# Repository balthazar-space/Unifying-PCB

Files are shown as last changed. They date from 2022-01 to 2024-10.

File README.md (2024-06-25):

# Balthazar

Open-hardware laptop computer modules description and concept.

These are electronic schematic modules as presented at https://balthazar.space/wiki/Balthazar with the main aim for team access. See the [main repository](https://github.com/balthazar-space/balthazar) for other designs.

# Unifying-PCB

Unifying PCB expansion for Balthazar 

Single PCB solution for connecting the three previously designed Balthazar modules (I/O, power supply, USB 2.0, 3.0 controllers, keyboard and adding Compute Module compatible FPGA boards. Aimed at setting a compatibility standard to widely accepted hardware standards.
It has standardized 100 pin accomodating module for adding standard CM HAT modules based on ARM or FPGA 
It has GPIO expansion port, HDMI,2x USB 3.0, Ethernet RJ45 and a microSD card slot.  

It is designed to accomodate ULX4M-CM4-HAT designed by Radiona.org using HDR 100 POS SMT board to board mezzanine connectors.

dimensions: 120x80 mm
placement: right back side of Balthazar casing

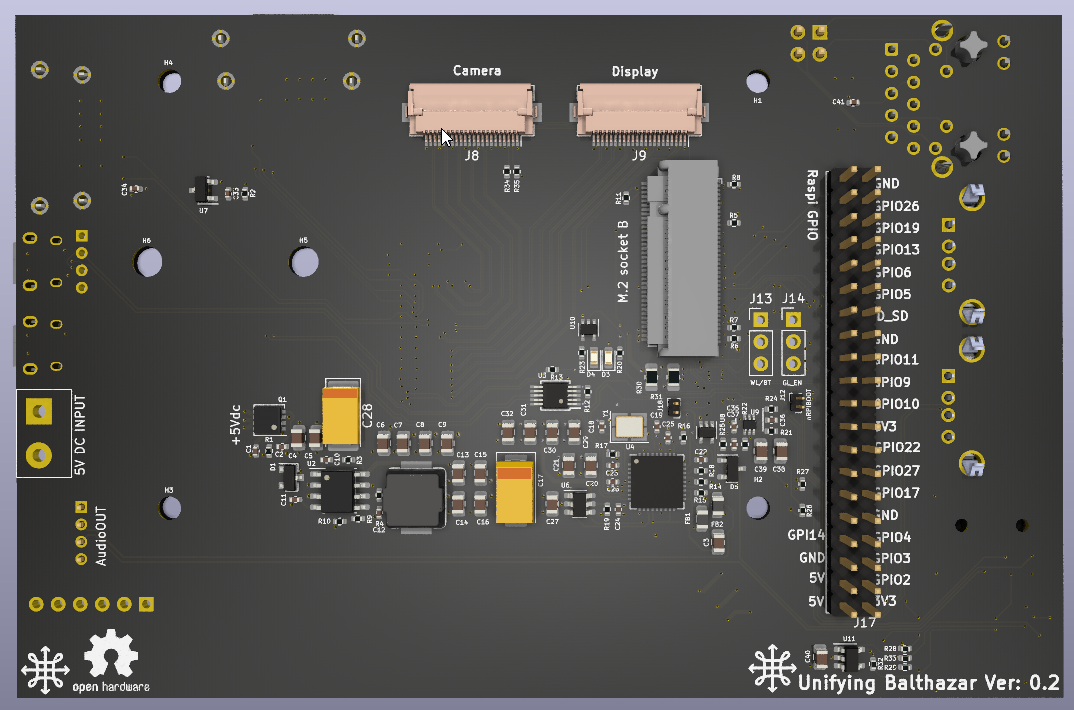
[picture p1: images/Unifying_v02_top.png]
TOP


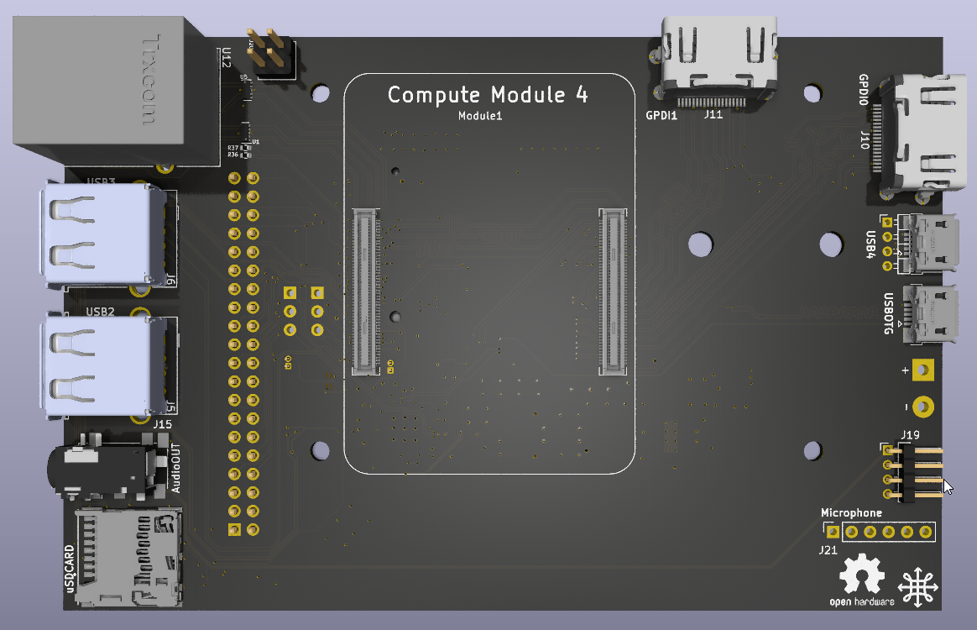
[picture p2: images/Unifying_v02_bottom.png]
BOTTOM


## License

All resources except the keyboard firmware - which is licensed with with GPLv3 or later - licensed under the CERN Open Hardware Licence CERN-OHL W V.2.0

Version 2.0 of the CERN-OHL introduces three variants of the licence – strongly (S) reciprocal, weakly (W) reciprocal and permissive (P) – which aim to address specific constraints caused by different collaboration models currently used in open-hardware projects. 

The first two variants mean that if any product is made using an open hardware design, the design of that product, including any improvements or modifications, should be made available under the same licence as that of the original product. Permissive licences do not impose this condition.

See the [LICENSE.md](./LICENSE.md) file for more information.

## Funding

This project is funded through the [NGI Zero Entrust Fund](https://nlnet.nl/entrust), a fund
established by [NLnet](https://nlnet.nl) with financial support from the European Commission's
[Next Generation Internet](https://ngi.eu) program. Learn more on the [NLnet project page](https://nlnet.nl/project/Balthazar-Casing/).

[NLNet foundation logo](https://nlnet.nl)
[NGI0 Entrust Logo](https://nlnet.nl/entrust)

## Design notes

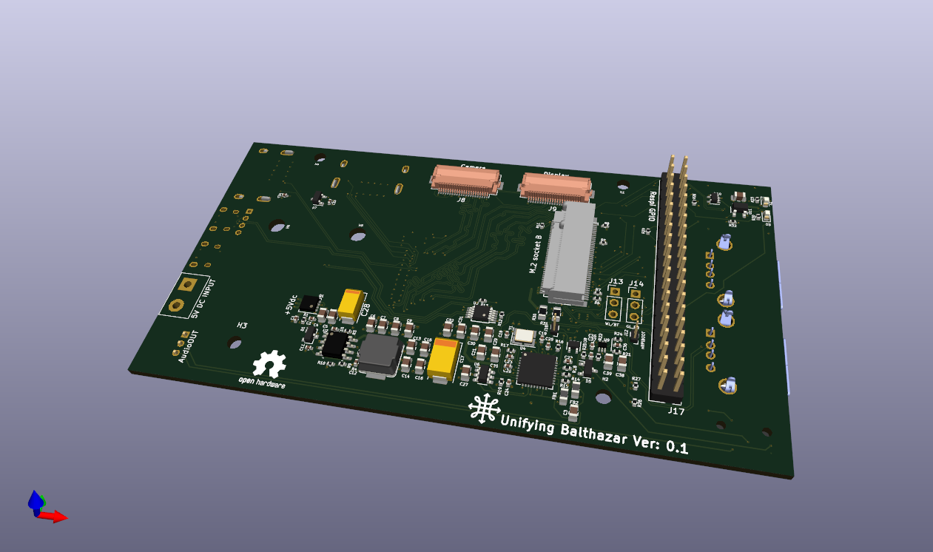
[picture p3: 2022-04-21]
images/UnifyingTOP.png

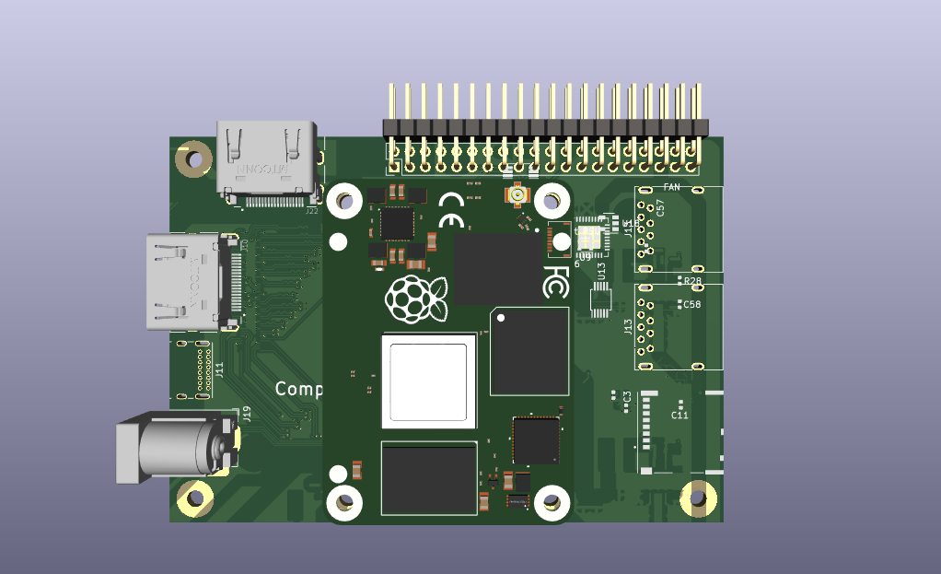
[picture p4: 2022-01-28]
images/balthazar-CM4IO-img01.png

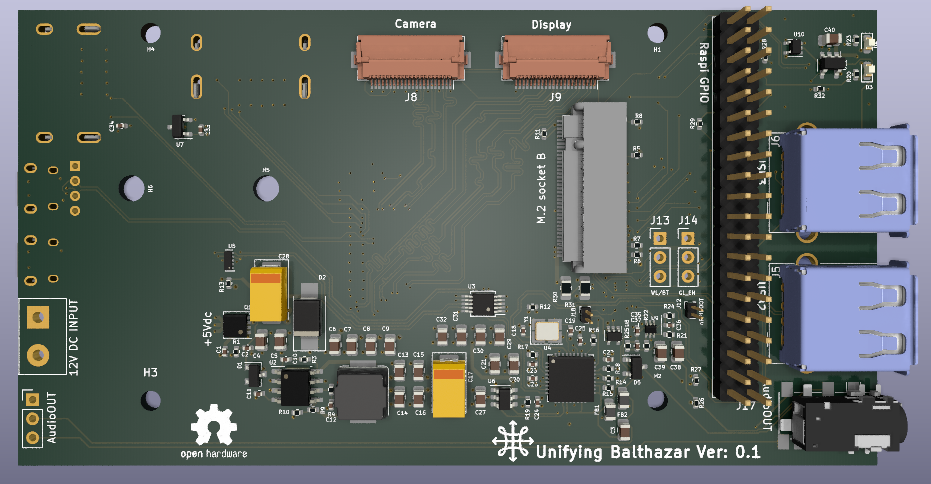
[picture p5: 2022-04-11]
images/balthazar-CM4IO-img_top.png

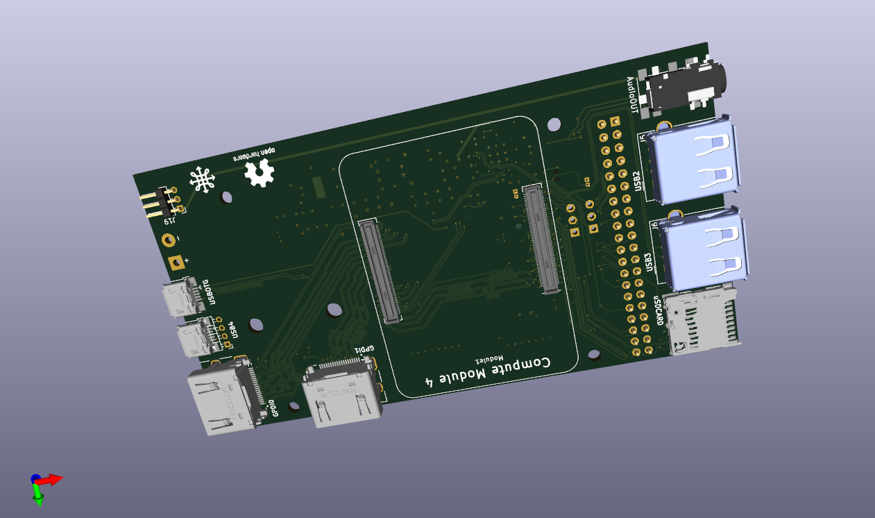
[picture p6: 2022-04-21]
images/UnifyingBOT.png

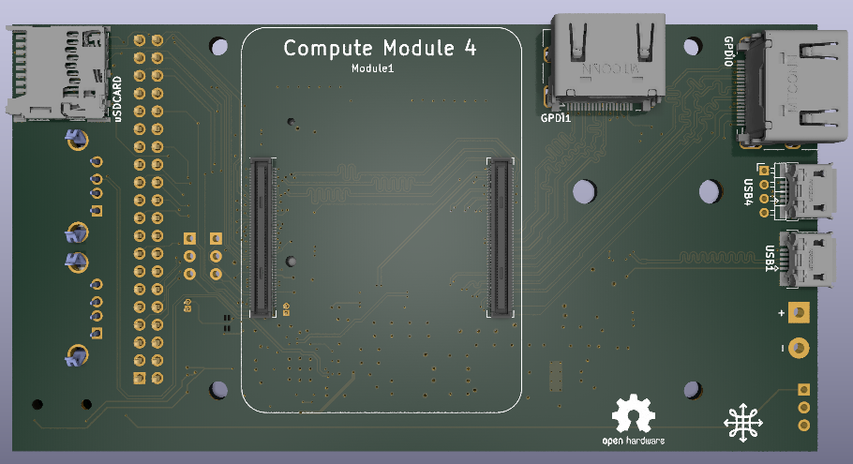
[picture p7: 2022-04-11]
images/balthazar-CM4IO-img_bottom.png

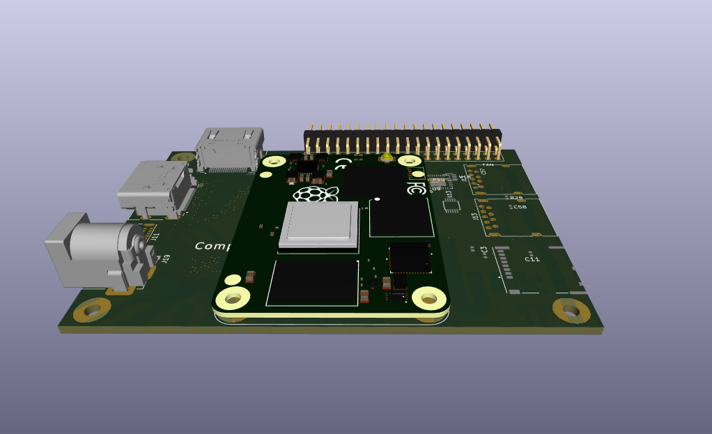
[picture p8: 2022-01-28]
images/balthazar-CM4IO-img02.png

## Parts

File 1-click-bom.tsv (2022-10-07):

References | Qty | Description | Manufacturer | MPN | Manufacturer | MPN | Digikey | Mouser | RS | Newark | Farnell | LCSC | JLC Assembly
C3, C13, C14, C15, C16, C20, C21, C27, C29, C30, C31, C32, C40 | 13 | 10u C_0805_2012Metric | KYOCERA AVX | 08053D106KAT4A |  | 08053D106KAT4A | 478-08053D106KAT4ACT-ND | 58108053D106KAT4A |  |  | 3922206
C2, C10, C11, C22, C23, C24, C25, C26, C33, C34 | 10 | 100n C_0402_1005Metric | AVX | 04025C104KAT4A |  | 04025C104KAT4A | 478-04025C104KAT4ACT-ND | 58104025C104KAT4A
C4, C5, C6, C7, C8, C9 | 6 | 10u 10v C_0805_2012Metric | Yageo | CC0805KKX5R6BB106 |  | CC0805KKX5R6BB106 | 311-1460-1-ND | 603CC805KKX5R6BB106 | 1988064 |  | 9402136
C35, C36, C37 | 3 | 100n 6.3 C_0402_1005Metric | KYOCERA AVX | 04026D104KAT4A |  | 04026D104KAT4A | 478-11504-1-ND | 58104026D104KAT4A
C18, C19 | 2 | 27pF C_0402_1005Metric |  | GCM1555C1H270FA16D |  |  |  | 81GCM1555C1H270FA6D
C38, C39 | 2 | 47u 6.3 C_0805_2012Metric | KYOCERA AVX | 08056D476MAT2A |  | 08056D476MAT2A | 478-08056D476MAT2ACT-ND | 58108056D476MAT2A
C1 | 1 | 100n 50v C_0402_1005Metric | AVX | 04025C104KAT4A |  | 04025C104KAT4A | 478-04025C104KAT4ACT-ND | 58104025C104KAT4A
C12 | 1 | 1.2nF C_0402_1005Metric | KEMET | C0402C122J5GACTU |  | C0402C122J5GACTU | 399-C0402C122J5GAC7867CT-ND | 80C0402C122J5G |  |  | 1800803
C17 | 1 | 100uF CP_EIA-7343-31_Kemet-D |  | 293D107X06R3D2TE3 |  |  |  | 74293D107X06R3D2TE3
C28 | 1 | 100uF CP_EIA-7132-20_AVX-U |  |  |  |  |  | 74293D107X06R3D2TE3
R5, R6, R7, R8, R28, R29 | 6 | nf R_0402_1005Metric
R1, R4, R17, R32 | 4 | 12K 1% R_0402_1005Metric | Vishay | PTN0402E1202BST1 |  | PTN0402E1202BST1 |  | 71PTN0402E1202BST1
R14, R15, R16, R18 | 4 | 36K 1% R_0402_1005Metric | Yageo | RT0402FRE0736KL |  | RT0402FRE0736KL | 13-RT0402FRE0736KLCT-ND | 603RT0402FRE0736KL
R10, R19 | 2 | 15K 1% R_0402_1005Metric | Yageo | RT0402FRE0715KL |  | RT0402FRE0715KL | YAG5930DKR-ND | 603RT0402FRE0715KL
R12, R13 | 2 | 2.2K 1% R_0402_1005Metric | Yageo | RT0402FRE072K2L |  | RT0402FRE072K2L | 13-RT0402FRE072K2LDKR-ND | 603RT0402FRE072K2L |  |  | 3496566
R20, R23 | 2 | 1k R_0402_1005Metric | Bourns | CRT0402-BY-1001GLF |  | CRT0402-BY-1001GLF | 118-CRT0402-BY-1001GLFCT-ND | 652CRT0402BY1001GLF
R21, R22 | 2 | 220 R_0402_1005Metric | Panasonic | ERA-2VEB2200X |  | ERA-2VEB2200X | 10-ERA-2VEB2200XDKR-ND | 667ERA2VEB2200X | 2413248 |  | 3482112
R24, R25 | 2 | 100 R_0402_1005Metric | Vishay | MCS04020D1000BE000 |  | MCS04020D1000BE000 | 749-MCS04020D1000BE000CT-ND | 594MCS04020D1000BE0
R26, R27 | 2 | 1K8 R_0402_1005Metric | TE Connectivity | CPF0402B1K8E1 |  | CPF0402B1K8E1 | A102697CT-ND | 279CPF0402B1K8E1 |  |  | 1697323
R3 | 1 | 10R R_0402_1005Metric | TE Connectivity | CPF0402B10RE1 |  | CPF0402B10RE1 | A102583DKR-ND | 279CPF0402B10RE1 | 1226344 |  | 1697292
R9 | 1 | 47K 1% R_0402_1005Metric | Yageo | AT0402FRE0747KL |  | AT0402FRE0747KL |  | 603AT0402FRE0747KL
R11 | 1 | 12K R_0402_1005Metric | Yageo | AT0402FRE0712KL |  | AT0402FRE0712KL |  | 603AT0402FRE0712KL
R30 | 1 | 0R R_0805_2012Metric_Pad1.20x1.40mm_HandSolder | Yageo | RC0603JR-070RL |  |  | 311-0.0GRCT-ND | 603RC0603JR070RL | 1995647P |  | 9233130
R31 | 1 | nf R_0805_2012Metric_Pad1.20x1.40mm_HandSolder
L2 | 1 | SRN6045TA-3R3Y | Bourns | SRN6045TA-3R3Y |  |  | SRN6045TA-3R3YCT-ND | 652SRN6045TA3R3Y |  |  | 2616889
D1 | 1 | MMBZ5242BLT3G D_SOT-23_ANK | onsemi | MMBZ5242BLT3G |  | MMBZ5242BLT3G | MMBZ5242BLT3GOSDKR-ND | 863MMBZ5242BLT3G |  |  | 3607004
D3 | 1 | LED Green LED_0603_1608Metric | Vishay | VLMTG1401-GS08 |  | VLMTG1401-GS08 | 751-VLMTG1401-GS08TR-ND | 78VLMTG1401GS08
D4 | 1 | LED Red LED_0603_1608Metric | Vishay | VLMS1300-GS08 |  | VLMS1300-GS08 | VLMS1300-GS08DKR-ND | 78VLMS1300GS08 | 7730458P |  | 2251484
D5 | 1 | BAV99 SOT-23 | Comchip | BAV99-HF |  | BAV99-HF | 641-BAV99-HFCT-ND | 750BAV99HF
U8, U10 | 2 | 74LVC1G07SE-7 | Diodes Inc. | 74LVC1G07SE-7 | Diodes Inc. | 74AHC1G126SE-7 | 74AHC1G126SE-7DIDKR-ND | 62174AHC1G126SE7 | 7512793 |  | 1893811RL
U2 | 1 | AP64501SP-13 SOIC-8-1EP_3.9x4.9mm_P1.27mm_EP2.95x4.9mm_Mask2.71x3.4mm_ThermalVias | Diodes Inc. | AP64501SP-13 |  | AP64501SP-13 | 31-AP64501SP-13CT-ND | 621AP64501SP13 |  |  | 3518317
U3 | 1 | FSUSB42MUX MSOP-10_3x3mm_P0.5mm | onsemi | FSUSB42MUX |  | FSUSB42MUX | FSUSB42MUXDKR-ND | 512FSUSB42MUX | 7395144P |  | 2564479
U4 | 1 | USB2514B | Microchip | USB2514B-AEZC-TR |  |  | USB2514B-AEZC-CT-ND | 886USB2514BAEZCTR | 1779732 |  | 2775061
U6 | 1 | AP22653W6 SOT-23-6 | Diodes Inc. | AP22653W6-7 |  | AP22653W6-7 | 31-AP22653W6-7DKR-ND | 621AP22653W67 |  |  | 3755402
U7 | 1 | RT9742SNGV | Richtek | RT9742SNGV |  |  | 1028-RT9742SNGVDKR-ND
U9 | 1 | NC7WZ16 SC-88-6_2x2.1mm | onsemi | SN74AUP2G06DCKR |  | SN74AUP2G06DCKR | 595-SN74AUP2G06DCKR | 512NC7WZ16FHX |  |  | 3609115
U11 | 1 | RT9742GGJ5 SOT-23-5 | Richtek | RT9742GGJ5 |  | RT9742GGJ5 | 1028-1436-6-ND |  |  |  | 2545875
Y1 | 1 | 24MHz Crystal_SMD_EuroQuartz_X22-4Pin_5x3.2mm |  | ECS-5032MV-240-CN-TR |  |  |  | 520-5032MV-240-CNT
FB1, FB2 | 2 | FerriteBead L_0805_2012Metric | Fair-Rite | 2508051017Y0 |  | 2508051017Y0 | 1934-1435-1-ND | 6232508051017Y0 |  |  | 1781234
Module1 | 2 | ComputeModule4 Raspberry-Pi-4-Compute-Module-noholes | Hirose | DF40C-100DS-0.4V(51) |  | DF40C-100DS-0.4V(51) | H11615TR-ND | 798DF40C100DS0.4V51 |  |  | 2427679
Q1 | 1 | DMP3013SFV-7 Diodes_PowerDI3333-8 | Diodes Inc. | DMP3013SFV-7 |  | DMP3013SFV-7 | DMP3013SFV-7DITR-ND | 621DMP3013SFV7 |  |  | 3405192
J5, J6 | 2 | USB_A USB_A_Molex_67643_Horizontal | Molex | 67643-0910 |  | 67643-0910 | WM4993-ND | 538676430910 | 8006839 |  | 1450206
J8, J9 | 2 | Conn_01x22_Female Hirose_FH12-22S-0.5SH_1x22-1MP_P0.50mm_Horizontal |  | FH12-22S-0.5SH(55) |  | FH12-22S-0.5SH(55) | HFJ122CT-ND | 798FH1222S0.5SH55 | 7727049
J10, J11 | 2 | HDMI_C_1.4 EDAC 690-019-298-412 | EDAC | 690-019-298-412 |  | 208658-1051 |  | 5382086581051
J13, J14 | 2 | Conn_01x03 PinHeader_1x03_P2.54mm_Vertical |  | 61300311121 |  |  |  | 71061300311121
J1 | 1 | Conn_01x02 TerminalBlock_bornier-2_P5.08mm |  | OQ0254500000G |  |  |  | 649OQ02545000J0G
J2 | 1 | Bus_M.2_Socket_B Conn_TE-M.2-0.5-67P-doublesided | TE Connectivity | 2199230-4 |  | 2199230-4 | A115904DKR-ND | 57121992304 | 2411331 |  | 3398678
J3 | 1 | USB_OTG USB_Micro-B_EDAC_UCON00686 |  | USB3505-30-A |  |  |  | 640USB350530A
J4 | 1 | Conn_01x04_Male PinHeader_1x04_P2.00mm_Horizontal |  | SQT-104-01-F-S-RA |  |  |  | 200SQT10401FSRA
J7 | 1 | USB_MICRO USB_Micro-B_EDAC_UCON00686 |  | 47346-0001 |  |  |  | 538-47346-0001
J12 | 1 | nRpiBoot PinHeader_1x02_P1.00mm_Vertical
J15 | 1 | AudioOUT Jack_3.5mm_PJ311_Horizontal |  | SJ-43516-SMT-TR |  |  |  | 490SJ43515RSSMTTR
J16 | 1 | Micro_SD_Card_Det SDCARD_MOLEX_503398-1892 | Molex | 503398-1892 |  | 503398-1892 | WM11190CT-ND | 5385033981892 | 8801277P |  | 2358234
J17 | 1 | THD-20-R PinHeader_2x20_P2.54mm_Vertical | Hirose | 68683-220LF |  |  |  | 64968683220LF
J18 | 1 | GLOBAL_EN PinHeader_1x02_P1.00mm_Vertical
J19 | 1 | AudioAMP PinHeader_1x04_P2.00mm_Horizontal |  | M20-9990446 |  |  |  | 855M209990446

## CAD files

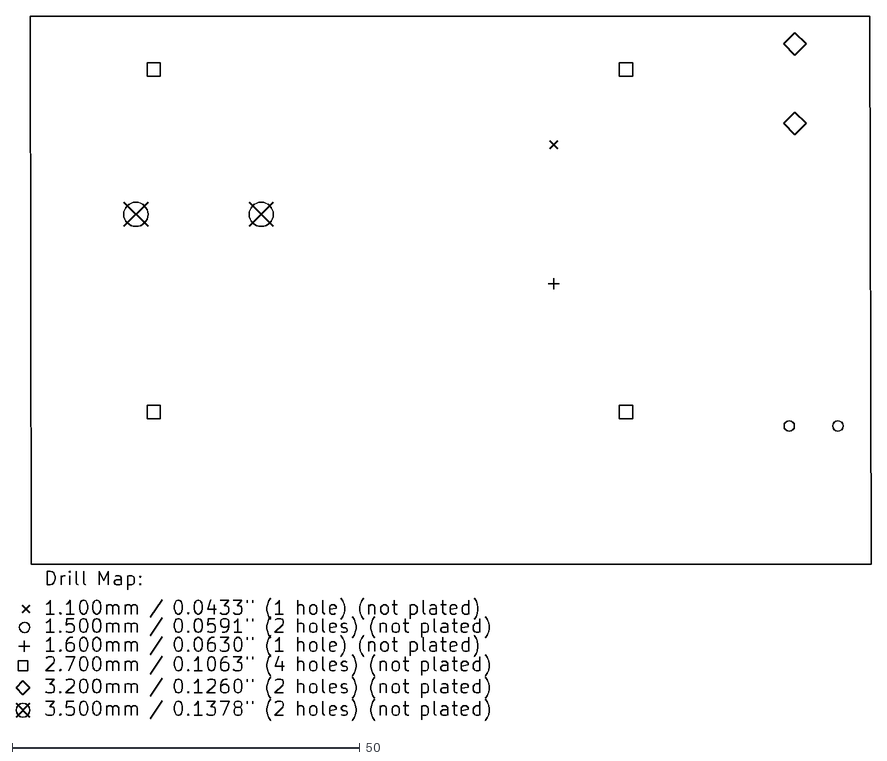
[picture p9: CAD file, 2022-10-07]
kicad/gerbers/Unifying-NPTH-drl_map.dxf
123.0 x 101.2

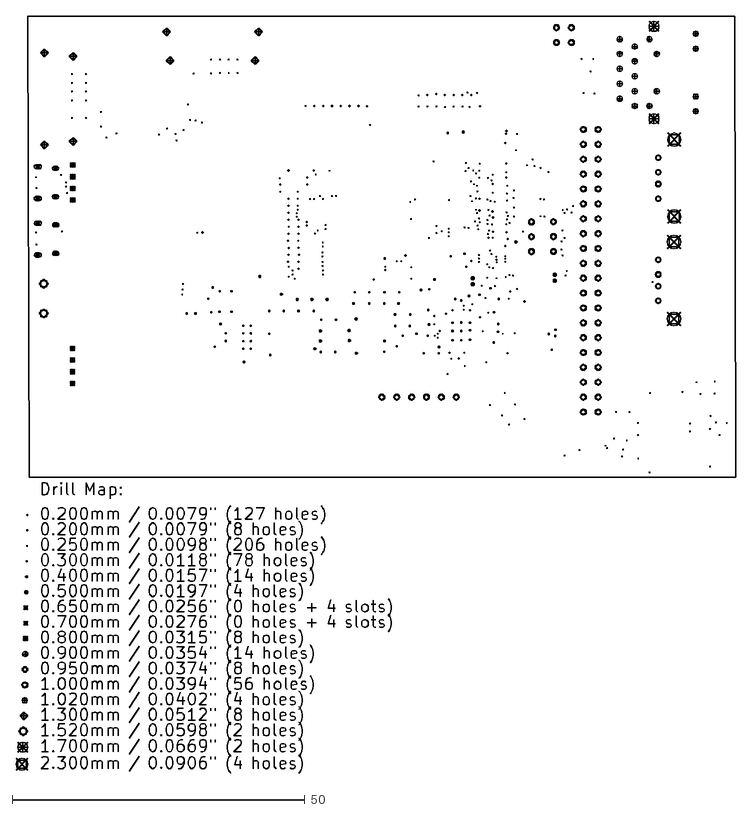
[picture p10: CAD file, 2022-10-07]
kicad/gerbers/Unifying-PTH-drl_map.dxf
123.0 x 129.3

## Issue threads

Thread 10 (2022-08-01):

USB connector is wrong in BOM

goran-mahovlic, 2022-08-01:

Closed 2022-10-07.

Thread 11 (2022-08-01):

Be aware of bricked 3.3V

goran-mahovlic, 2022-08-01:
As #5 display connector is inverted, if screen is connected 3.3V will brick to GND.
That will result in burning CM4 power supply chip.

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

goran-mahovlic, 2022-10-05:
DSI connector was rotated, this should be fixed in V02

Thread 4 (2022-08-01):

CAM - DISPL I2C is missing pullups (SDA0, SCL0)

goran-mahovlic, 2022-08-01:

Closed 2022-10-06.

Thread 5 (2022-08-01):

DISP and CAM connectors are mirrored

goran-mahovlic, 2022-08-01:
On schematics we need to vertical mirror connector.
On PCB that will be horizontal mirror.

goran-mahovlic, 2022-08-01:
Quick fix should look something like this
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

Closed 2022-10-05.

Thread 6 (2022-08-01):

Bottom side of the board was missing silkscreen

goran-mahovlic, 2022-08-01:

goran-mahovlic, 2022-10-06:
Silk screen layer is now turned on

Closed 2022-10-06.

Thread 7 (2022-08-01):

HDMI quality is really bad

goran-mahovlic, 2022-08-01:
I can hardly get any picture.

I have connected 5V directly to HDMI - usually we are using switch - maybe that added noise.

If not then we need to rework fast HDMI lines.

goran-mahovlic, 2022-10-06:
Should be fixed now, it was bad because wrong footprint

Closed 2022-10-06.

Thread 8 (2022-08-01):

Y1 in BOM list has wrong footprint

goran-mahovlic, 2022-08-01:

Closed 2022-10-07.

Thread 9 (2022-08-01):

U9 in a BOM list has wrong footprint

goran-mahovlic, 2022-08-01:

Closed 2022-10-07.

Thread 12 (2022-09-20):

HDMI has wrong footprint/simbol

goran-mahovlic, 2022-09-20:
I have recheck all connections and they are fine, but connector we have placed needs different connections...

I can see that first diff pair on CM4 IO board starts from pin1 and on our board with same connector starts from pin2 ...

We need to change symbol or footprint that will probably also  solve  #7

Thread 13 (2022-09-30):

Ethernet connector is missing

goran-mahovlic, 2022-09-30:
If there is enough space we should add one

Closed 2022-10-06.

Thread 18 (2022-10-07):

For EMC it would be best if we could switch to 6 leyer board

goran-mahovlic, 2022-10-07:
May not be important right now, but signal integrity would be improved if we switch to 6 layer board.
Currently some GPIO pins are routed on Power layer.
As we have only one GND plane signals on TOP layer are closer to the GND layer then those on BOTTOM layer...

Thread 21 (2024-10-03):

Printed schematics

prasimix, 2024-10-03:
It would be good if there were schematics so that one does not necessarily need to have KiCad installed to see it. I also suggest that in addition to or instead of print, you also make a plot in pdf, because such a version is searchable.

Closed 2024-10-17.

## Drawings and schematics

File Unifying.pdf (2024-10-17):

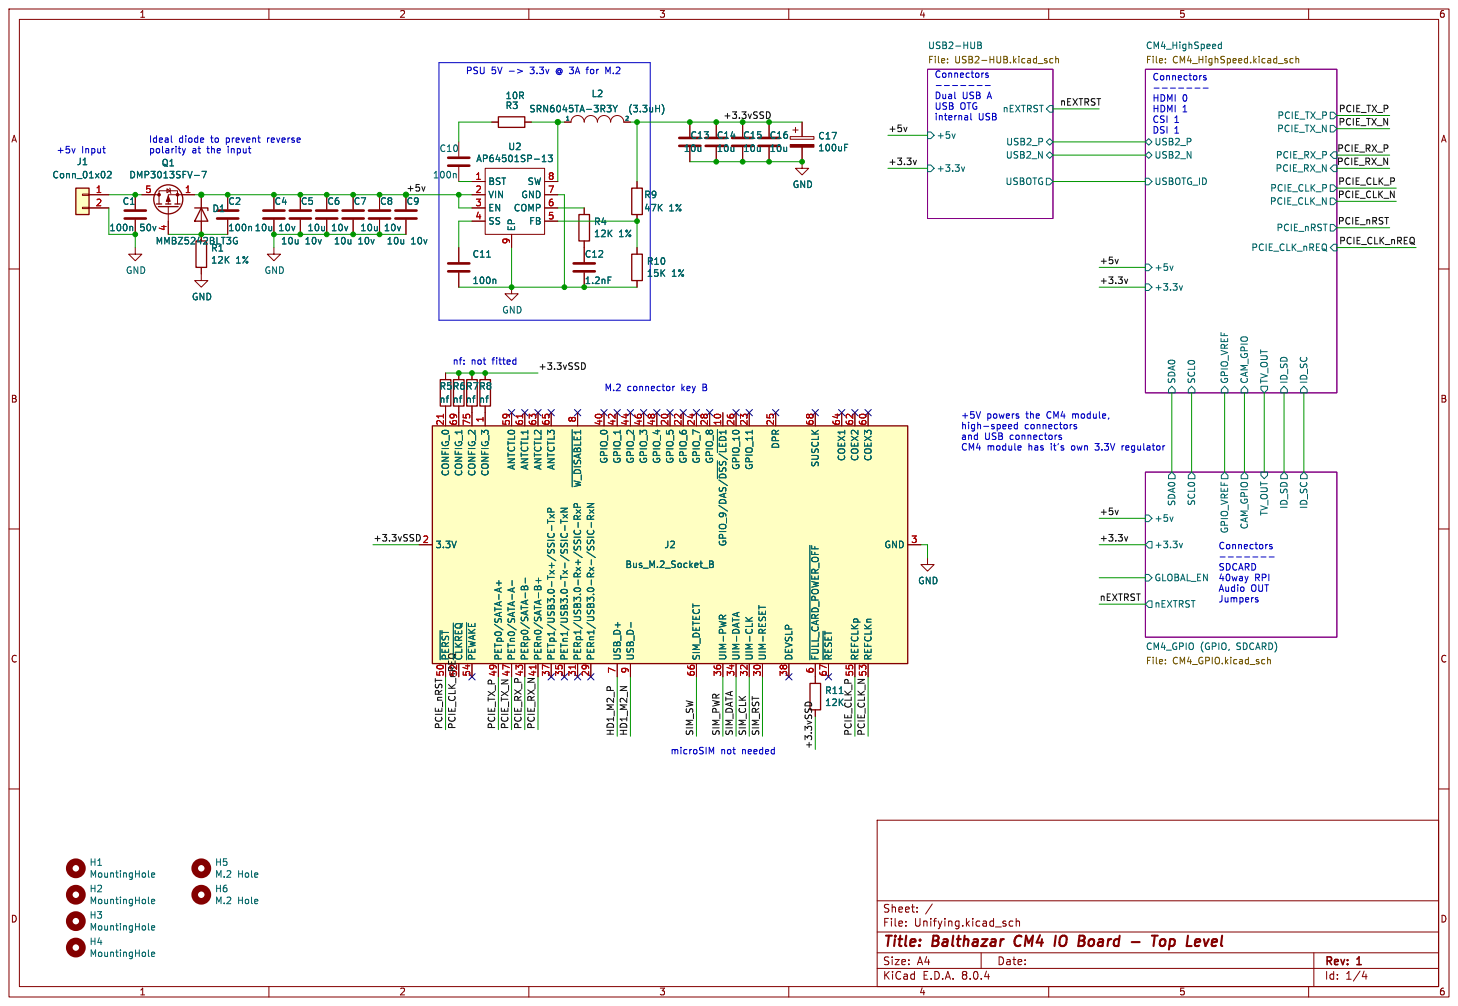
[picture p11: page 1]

------- Dual USB A USB OTG

Ideal diode to prevent reverse
5 Q1 DMP3013SFV-7 C1

Id: 1/4 Title: Balthazar CM4 IO Board - Top Level File: Unifying.kicad_sch Sheet: /

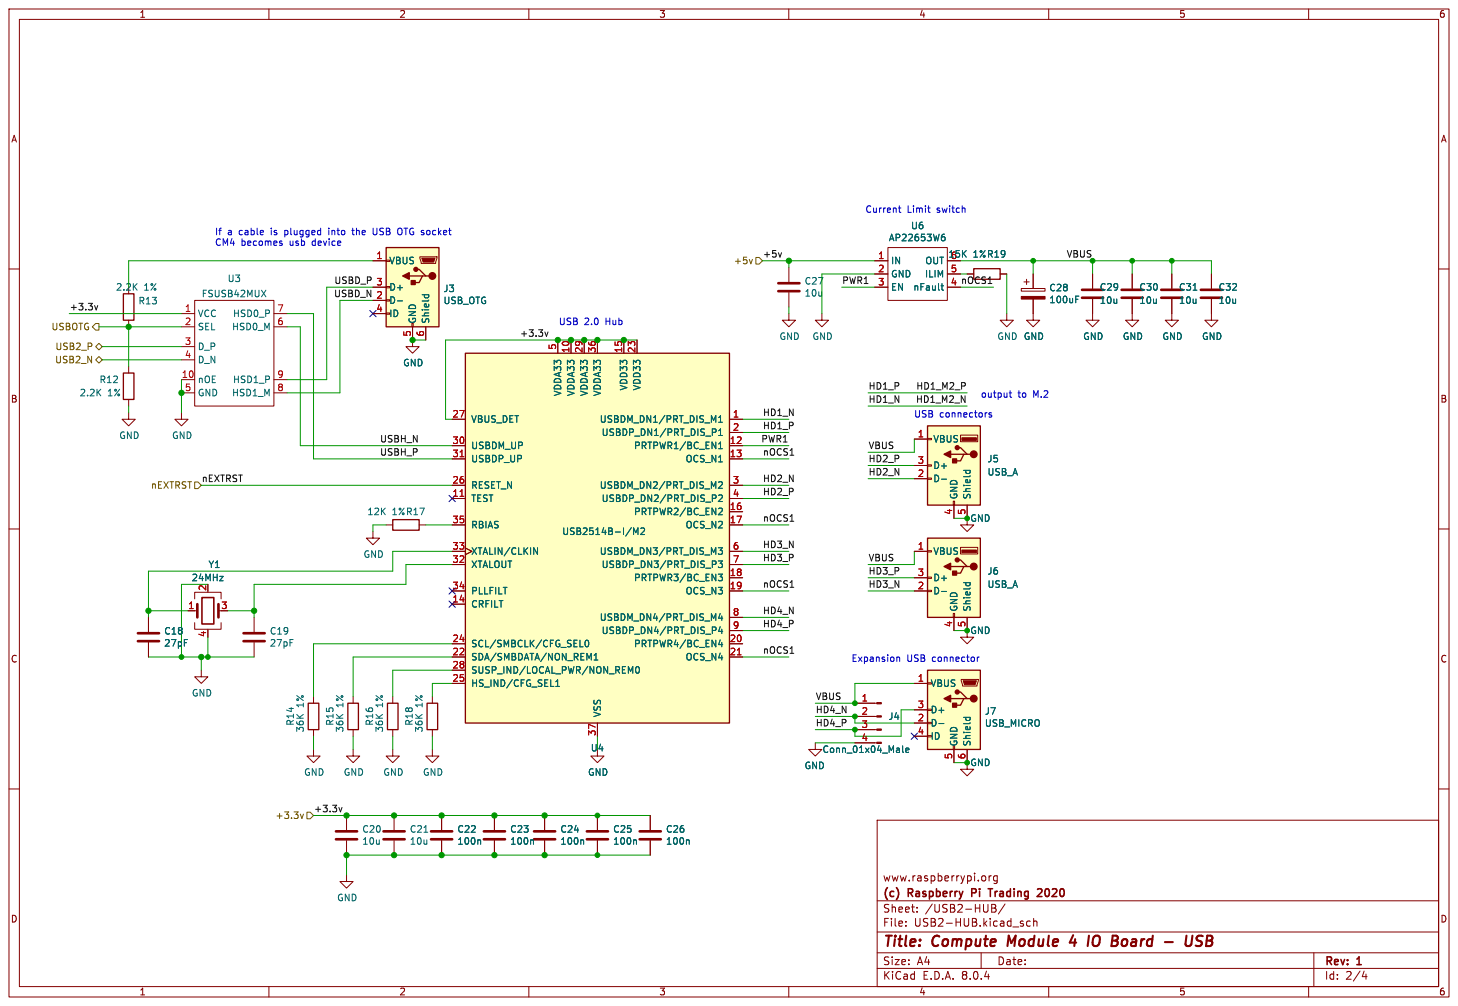
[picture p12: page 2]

ILIM 5 OUT 6 U6 AP22653W6 VCC 1
If a cable is plugged into the USB OTG socket CM4 becomes usb device

output to M.2 Expansion USB connector C22

Id: 2/4 Title: Compute Module 4 IO Board - USB

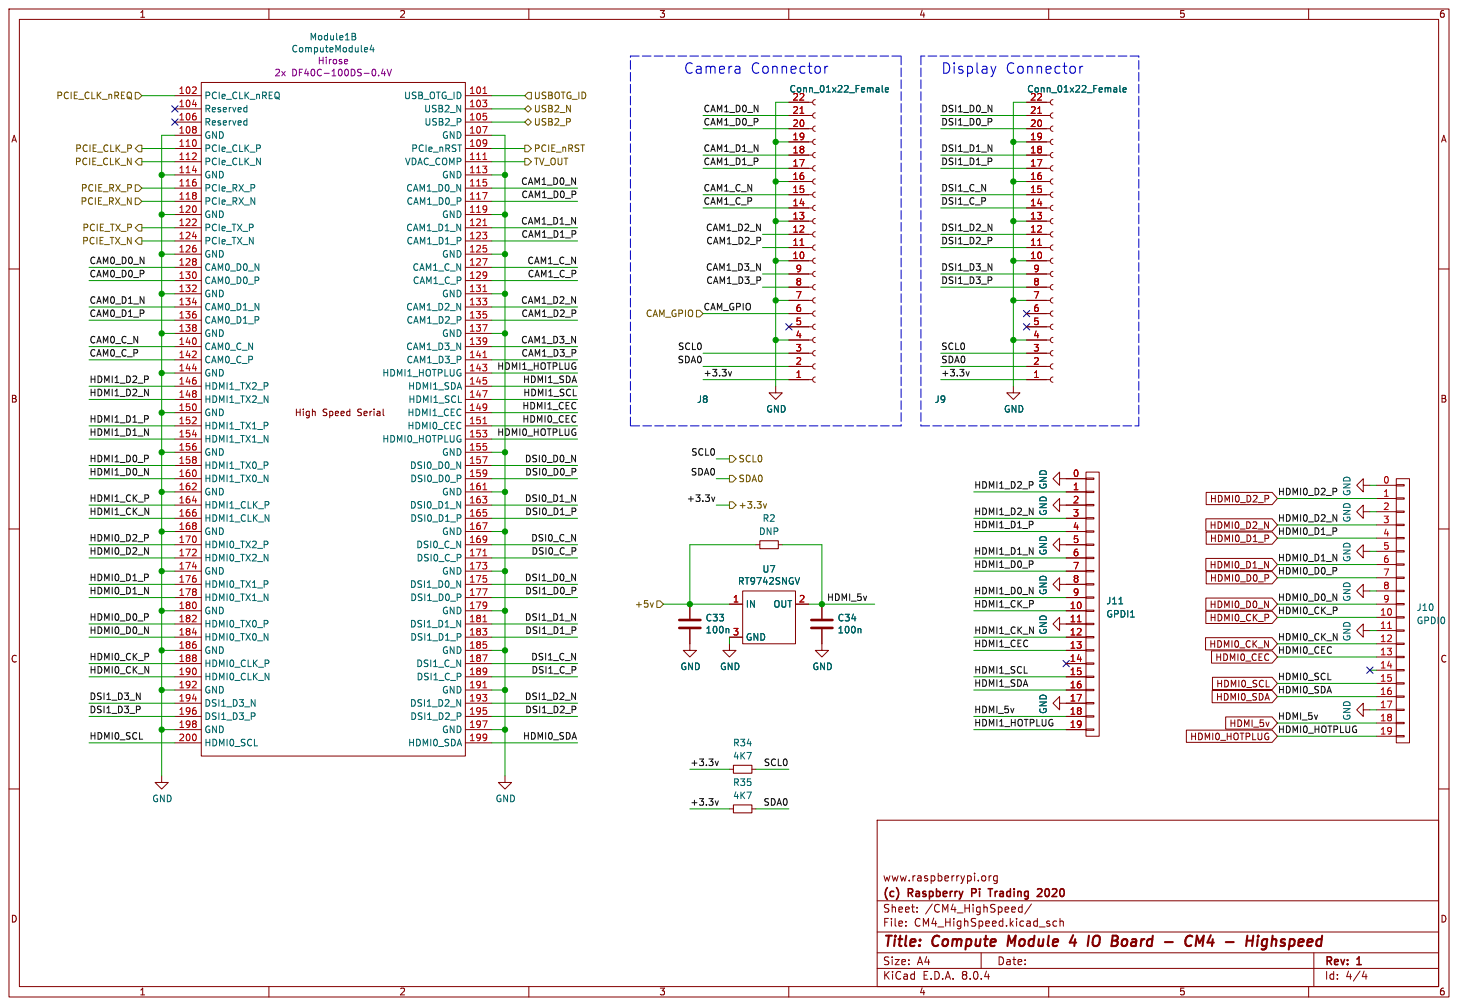
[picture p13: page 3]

File: CM4_HighSpeed.kicad_sch Sheet: /CM4_HighSpeed/
Id: 4/4 Title: Compute Module 4 IO Board - CM4 - Highspeed

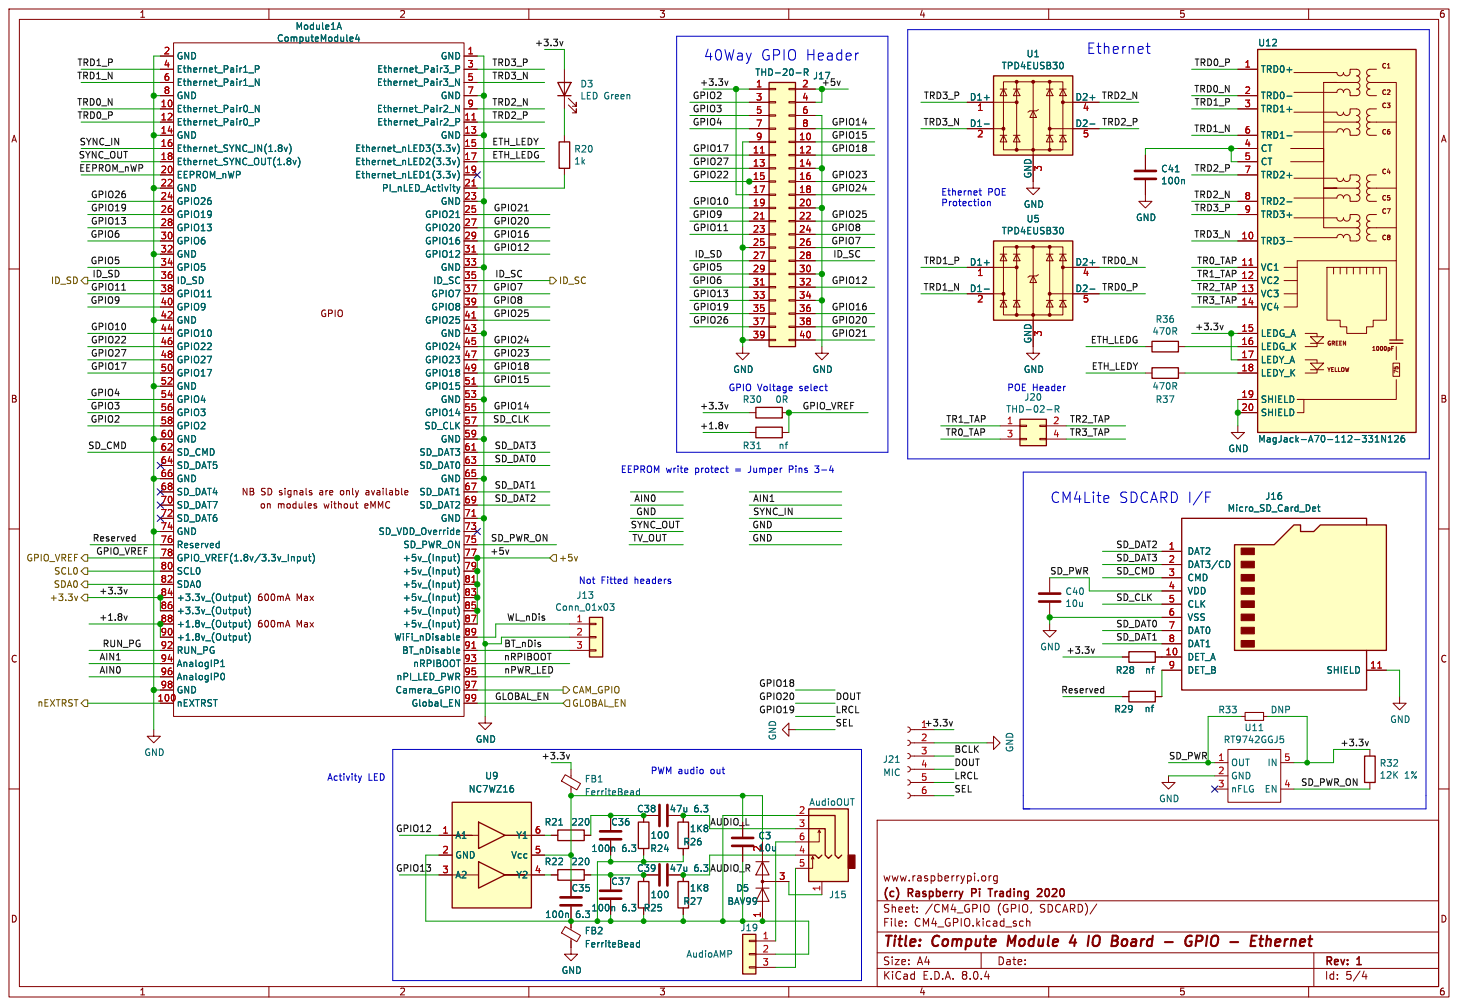
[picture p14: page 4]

600mA Max 600mA Max NB SD signals are only available

Id: 5/4 Title: Compute Module 4 IO Board - GPIO - Ethernet File: CM4_GPIO.kicad_sch Sheet: /CM4_GPIO (GPIO, SDCARD)/

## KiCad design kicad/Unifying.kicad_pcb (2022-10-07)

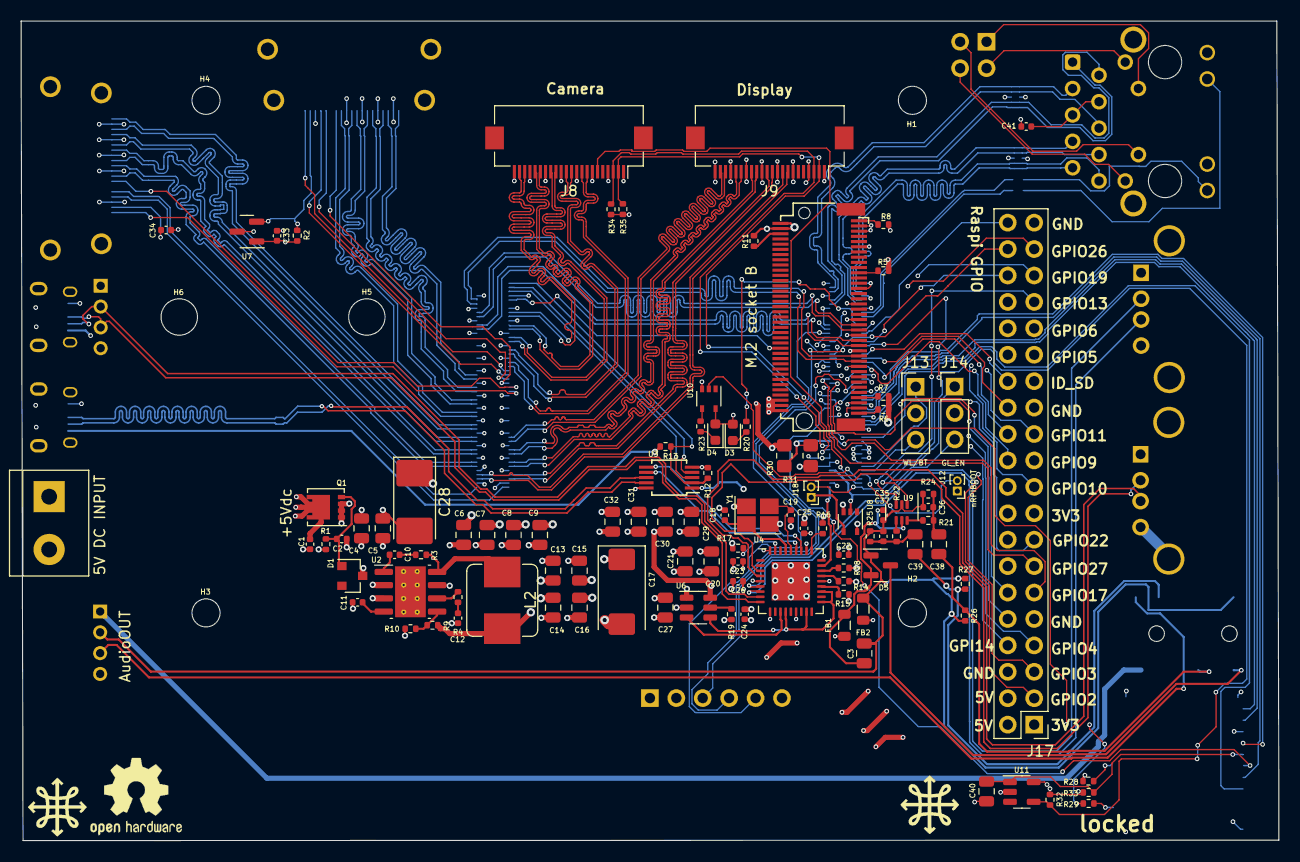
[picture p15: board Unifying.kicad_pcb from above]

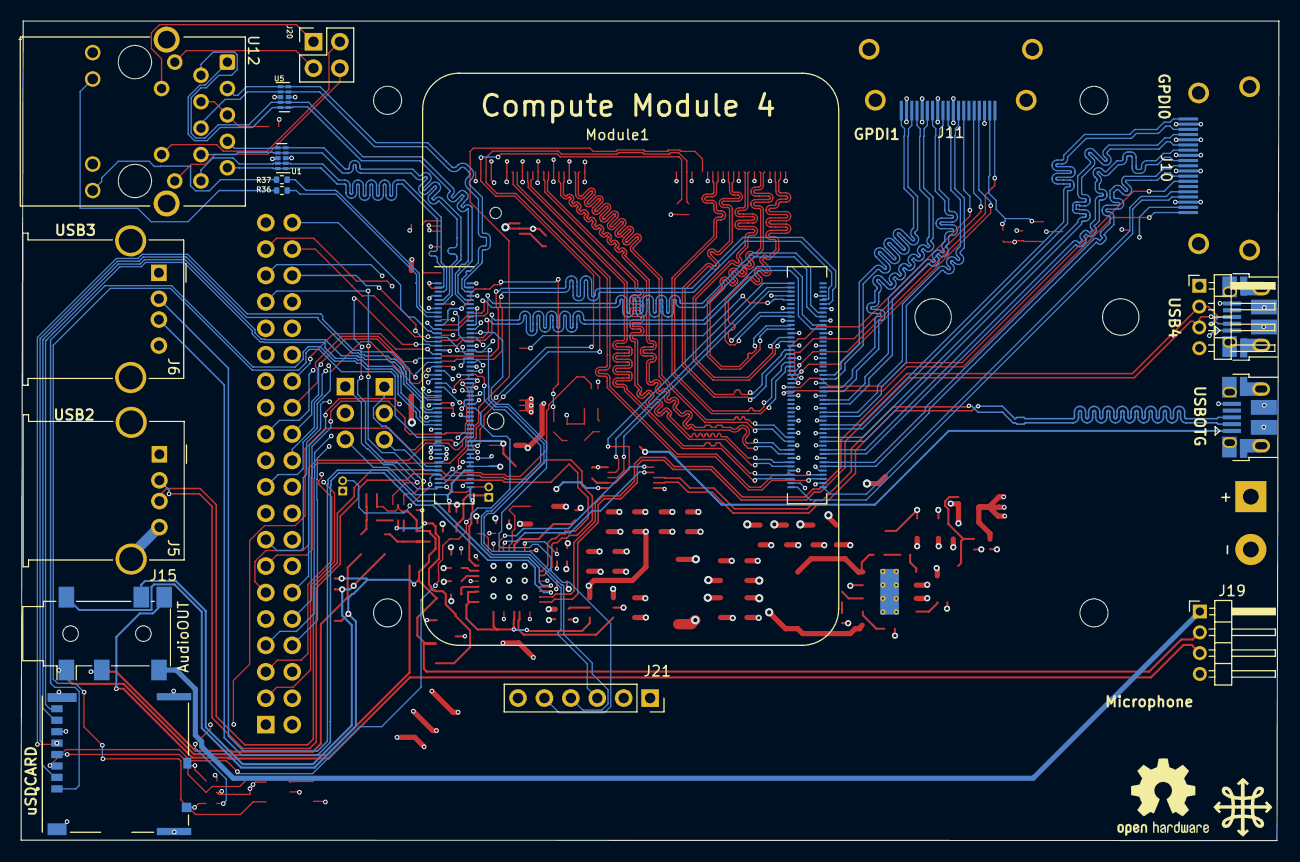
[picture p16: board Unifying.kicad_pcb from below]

Board: 4 copper layers, 120.9 x 78.8 mm, 127 parts (18 on the bottom side), 179 nets.

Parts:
C1: 100n 50v; C_0402_1005Metric
C2, C10, C11, C22, C23, C24, C25, C26, C33, C34, C41: 100n; C_0402_1005Metric
C3, C13, C14, C15, C16, C20, C21, C27, C29, C30, C31, C32, C40: 10u; C_0805_2012Metric
C4, C5, C6, C7, C8, C9: 10u 10v; C_0805_2012Metric
C12: 1.2nF; C_0402_1005Metric
C17: 100uF; CP_EIA-7343-31_Kemet-D
C18, C19: 27pF; C_0402_1005Metric
C28: 100uF; CP_EIA-7132-20_AVX-U
C35, C36, C37: 100n 6.3; C_0402_1005Metric
C38, C39: 47u 6.3; C_0805_2012Metric
D1: MMBZ5242BLT3G; D_SOT-23_ANK
D3: LED Green; LED_0603_1608Metric
D4: LED Red; LED_0603_1608Metric
D5: BAV99; SOT-23
FB1, FB2: FerriteBead; L_0805_2012Metric
H1, H2, H3, H4: MountingHole; MountingHole_2.7mm_M2.5
H5, H6: M.2 Hole; M.2Hole_3.5mm
J1: Conn_01x02; TerminalBlock_bornier-2_P5.08mm
J2: Bus_M.2_Socket_B; Conn_TE-M.2-0.5-67P-doublesided
J3: USB_OTG; USB_Micro-B_EDAC_UCON00686
J4: Conn_01x04_Male; PinHeader_1x04_P2.00mm_Horizontal
J5, J6: USB_A; USB_A_Molex_67643_Horizontal
J7: USB_MICRO; USB_Micro-B_EDAC_UCON00686
J8, J9: Conn_01x22_Female; Hirose_FH12-22S-0.5SH_1x22-1MP_P0.50mm_Horizontal
J10: GPDI0; CONN-10029449-111RLF
J11: GPDI1; CONN-10029449-111RLF
J12: nRpiBoot; PinHeader_1x02_P1.00mm_Vertical
J13, J14: Conn_01x03; PinHeader_1x03_P2.54mm_Vertical
J15: AudioOUT; Jack_3.5mm_PJ311_Horizontal
J16: Micro_SD_Card_Det; SDCARD_MOLEX_503398-1892
J17: THD-20-R; PinHeader_2x20_P2.54mm_Vertical
J18: GLOBAL_EN; PinHeader_1x02_P1.00mm_Vertical
J19: AudioAMP; PinHeader_1x04_P2.00mm_Horizontal
J20: THD-02-R; PinHeader_2x02_P2.54mm_Vertical
J21: MIC; PinSocket_1x06_P2.54mm_Vertical
L2: SRN6045TA-3R3Y (3.3uH); L_Bourns_SRP7028A_7.3x6.6mm
Module1: ComputeModule4; Raspberry-Pi-4-Compute-Module-noholes
Q1: DMP3013SFV-7; Diodes_PowerDI3333-8
R1, R4, R17, R32: 12K 1%; R_0402_1005Metric
R2, R33: DNP; R_0402_1005Metric
R3: 10R; R_0402_1005Metric
R5, R6, R7, R8, R28, R29: nf; R_0402_1005Metric
R9: 47K 1%; R_0402_1005Metric
R10, R19: 15K 1%; R_0402_1005Metric
R11: 12K; R_0402_1005Metric
R12, R13: 2.2K 1%; R_0402_1005Metric
R14, R15, R16, R18: 36K 1%; R_0402_1005Metric
R20, R23: 1k; R_0402_1005Metric
R21, R22: 220; R_0402_1005Metric
R24, R25: 100; R_0402_1005Metric
R26, R27: 1K8; R_0402_1005Metric
R30: 0R; R_0805_2012Metric_Pad1.20x1.40mm_HandSolder
R31: nf; R_0805_2012Metric_Pad1.20x1.40mm_HandSolder
R34, R35: 4K7; R_0402_1005Metric
R36, R37: 470R; R_0402_1005Metric
U1, U5: TPD4EUSB30; USON-10_2.5x1.0mm_P0.5mm
U2: AP64501SP-13; SOIC-8-1EP_3.9x4.9mm_P1.27mm_EP2.95x4.9mm_Mask2.71x3.4mm_Th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
U3: FSUSB42MUX; MSOP-10_3x3mm_P0.5mm
U4: USB2514B-I/M2; QFN-36-1EP_6x6mm_P0.5mm_EP3.7x3.7mm
U6: AP22653W6; SOT-23-6
U7: RT9742SNGV; SOT-23
U8, U10: 74LVC1G07SE-7; SOT-353_SC-70-5
U9: NC7WZ16; SC-88-6_2x2.1mm
U11: RT9742GGJ5; SOT-23-5
U12: MagJack-A70-112-331N126; TRJG0926HENL
Y1: 24MHz; Crystal_SMD_EuroQuartz_X22-4Pin_2.5x2.0mm_HandSoldering

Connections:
/+3.3v: C20.1, C21.1, C22.1, C23.1, C24.1, C25.1, C26.1, D3.2 (A), D4.2 (A), FB1.1, J8.1, J9.1, J17.1, J17.17, J21.1, Module1.84 (+3.3v_(Output)), Module1.86 (+3.3v_(Output)), R28.1, R30.1, R32.1, R33.2, R34.1, R35.1, U3.1 (VCC), U4.5 (VDDA33), U4.10 (VDDA33), U4.15 (VDD33), U4.23 (VDD33), U4.27 (VBUS_DET), U4.29 (VDDA33), U4.36 (VDDA33), U10.5 (VCC), U11.5 (IN), U12.15 (LEDG_A), U12.17 (LEDY_A)
/+3.3vSSD: C13.1, C14.1, C15.1, C16.1, C17.1, J2.2 (3.3V), J2.4 (3.3V), J2.70 (3.3V), J2.72 (3.3V), J2.74 (3.3V), L2.2, R5.1, R6.1, R7.1, R8.1, R9.1, R11.2
/+5v: C2.1, C4.1, C5.1, C6.1, C7.1, C8.1, C9.1, C27.1, C33.1, D1.1 (K), J17.2, J17.4, Module1.77 (+5v_(Input)), Module1.79 (+5v_(Input)), Module1.81 (+5v_(Input)), Module1.83 (+5v_(Input)), Module1.85 (+5v_(Input)), Module1.87 (+5v_(Input)), Q1.1 (S), Q1.2 (S), Q1.3 (S), R2.1, U2.2 (VIN), U2.3 (EN), U6.1 (IN), U7.1 (IN), U8.5 (VCC)
/CM4_GPIO (GPIO, SDCARD)/+1.8v: Module1.88 (+1.8v_(Output)), Module1.90 (+1.8v_(Output)), R31.1
/CM4_GPIO (GPIO, SDCARD)/AUDIO_L: C38.2, J15.3, R26.2
/CM4_GPIO (GPIO, SDCARD)/AUDIO_R: C39.2, J15.4, R27.2
/CM4_GPIO (GPIO, SDCARD)/BCLK: J17.12, J21.3, Module1.49 (GPIO18)
/CM4_GPIO (GPIO, SDCARD)/BT_nDis: J13.3, Module1.91 (BT_nDisable)
/CM4_GPIO (GPIO, SDCARD)/DOUT: J17.38, J21.4, Module1.27 (GPIO20)
/CM4_GPIO (GPIO, SDCARD)/ETH_LEDG: Module1.17 (Ethernet_nLED2(3.3v)), R36.2
/CM4_GPIO (GPIO, SDCARD)/ETH_LEDY: Module1.15 (Ethernet_nLED3(3.3v)), R37.2
/CM4_GPIO (GPIO, SDCARD)/GLOBAL_EN: J14.1, J18.2, Module1.99 (Global_EN)
/CM4_GPIO (GPIO, SDCARD)/GPIO2: J17.3, Module1.58 (GPIO2)
/CM4_GPIO (GPIO, SDCARD)/GPIO3: J17.5, Module1.56 (GPIO3)
/CM4_GPIO (GPIO, SDCARD)/GPIO4: J17.7, Module1.54 (GPIO4)
/CM4_GPIO (GPIO, SDCARD)/GPIO5: J17.29, Module1.34 (GPIO5)
/CM4_GPIO (GPIO, SDCARD)/GPIO6: J17.31, Module1.30 (GPIO6)
/CM4_GPIO (GPIO, SDCARD)/GPIO7: J17.26, Module1.37 (GPIO7)
/CM4_GPIO (GPIO, SDCARD)/GPIO8: J17.24, Module1.39 (GPIO8)
/CM4_GPIO (GPIO, SDCARD)/GPIO9: J17.21, Module1.40 (GPIO9)
/CM4_GPIO (GPIO, SDCARD)/GPIO10: J17.19, Module1.44 (GPIO10)
/CM4_GPIO (GPIO, SDCARD)/GPIO11: J17.23, Module1.38 (GPIO11)
/CM4_GPIO (GPIO, SDCARD)/GPIO12: J17.32, Module1.31 (GPIO12), U9.1 (A1)
/CM4_GPIO (GPIO, SDCARD)/GPIO13: J17.33, Module1.28 (GPIO13), U9.3 (A2)
/CM4_GPIO (GPIO, SDCARD)/GPIO14: J17.8, Module1.55 (GPIO14)
/CM4_GPIO (GPIO, SDCARD)/GPIO15: J17.10, Module1.51 (GPIO15)
/CM4_GPIO (GPIO, SDCARD)/GPIO16: J17.36, Module1.29 (GPIO16)
/CM4_GPIO (GPIO, SDCARD)/GPIO17: J17.11, Module1.50 (GPIO17)
/CM4_GPIO (GPIO, SDCARD)/GPIO21: J17.40, Module1.25 (GPIO21)
/CM4_GPIO (GPIO, SDCARD)/GPIO22: J17.15, Module1.46 (GPIO22)
/CM4_GPIO (GPIO, SDCARD)/GPIO23: J17.16, Module1.47 (GPIO23)
/CM4_GPIO (GPIO, SDCARD)/GPIO24: J17.18, Module1.45 (GPIO24)
/CM4_GPIO (GPIO, SDCARD)/GPIO25: J17.22, Module1.41 (GPIO25)
/CM4_GPIO (GPIO, SDCARD)/GPIO26: J17.37, Module1.24 (GPIO26)
/CM4_GPIO (GPIO, SDCARD)/GPIO27: J17.13, Module1.48 (GPIO27)
/CM4_GPIO (GPIO, SDCARD)/GPIO_VREF: Module1.78 (GPIO_VREF(1.8v/3.3v_Input)), R30.2, R31.2
/CM4_GPIO (GPIO, SDCARD)/ID_SC: J17.28, Module1.35 (ID_SC)
/CM4_GPIO (GPIO, SDCARD)/ID_SD: J17.27, Module1.36 (ID_SD)
/CM4_GPIO (GPIO, SDCARD)/LRCL: J17.35, J21.5, Module1.26 (GPIO19)
/CM4_GPIO (GPIO, SDCARD)/RUN_PG: J14.3, Module1.92 (RUN_PG), U8.2
/CM4_GPIO (GPIO, SDCARD)/Reserved: Module1.76 (Reserved), R29.1
/CM4_GPIO (GPIO, SDCARD)/SD_CLK: J16.5 (CLK), Module1.57 (SD_CLK)
/CM4_GPIO (GPIO, SDCARD)/SD_CMD: J16.3 (CMD), Module1.62 (SD_CMD)
/CM4_GPIO (GPIO, SDCARD)/SD_DAT0: J16.7 (DAT0), Module1.63 (SD_DAT0)
/CM4_GPIO (GPIO, SDCARD)/SD_DAT1: J16.8 (DAT1), Module1.67 (SD_DAT1)
/CM4_GPIO (GPIO, SDCARD)/SD_DAT2: J16.1 (DAT2), Module1.69 (SD_DAT2)
/CM4_GPIO (GPIO, SDCARD)/SD_DAT3: J16.2 (DAT3/CD), Module1.61 (SD_DAT3)
/CM4_GPIO (GPIO, SDCARD)/SD_PWR: C40.1, J16.4 (VDD), R33.1, U11.1 (OUT)
/CM4_GPIO (GPIO, SDCARD)/SD_PWR_ON: Module1.75 (SD_PWR_ON), R32.2, U11.4 (EN)
/CM4_GPIO (GPIO, SDCARD)/TR0_TAP: J20.3, U12.11 (VC1)
/CM4_GPIO (GPIO, SDCARD)/TR1_TAP: J20.1, U12.12 (VC2)
/CM4_GPIO (GPIO, SDCARD)/TR2_TAP: J20.2, U12.13 (VC3)
/CM4_GPIO (GPIO, SDCARD)/TR3_TAP: J20.4, U12.14 (VC4)
/CM4_GPIO (GPIO, SDCARD)/TRD0_N: Module1.10 (Ethernet_Pair0_N), U5.4 (D2+), U5.7, U12.2 (TRD0-)
/CM4_GPIO (GPIO, SDCARD)/TRD0_P: Module1.12 (Ethernet_Pair0_P), U5.5 (D2-), U5.6, U12.1 (TRD0+)
/CM4_GPIO (GPIO, SDCARD)/TRD1_N: Module1.6 (Ethernet_Pair1_N), U5.2 (D1-), U5.9, U12.6 (TRD1-)
/CM4_GPIO (GPIO, SDCARD)/TRD1_P: Module1.4 (Ethernet_Pair1_P), U5.1 (D1+), U5.10, U12.3 (TRD1+)
/CM4_GPIO (GPIO, SDCARD)/TRD2_N: Module1.9 (Ethernet_Pair2_N), U1.4 (D2+), U1.7, U12.8 (TRD2-)
/CM4_GPIO (GPIO, SDCARD)/TRD2_P: Module1.11 (Ethernet_Pair2_P), U1.5 (D2-), U1.6, U12.7 (TRD2+)
/CM4_GPIO (GPIO, SDCARD)/TRD3_N: Module1.5 (Ethernet_Pair3_N), U1.2 (D1-), U1.9, U12.10 (TRD3-)
/CM4_GPIO (GPIO, SDCARD)/TRD3_P: Module1.3 (Ethernet_Pair3_P), U1.1 (D1+), U1.10, U12.9 (TRD3+)
/CM4_GPIO (GPIO, SDCARD)/WL_nDis: J13.1, Module1.89 (WiFi_nDisable)
/CM4_GPIO (GPIO, SDCARD)/nPWR_LED: Module1.95 (nPI_LED_PWR), U10.2
/CM4_GPIO (GPIO, SDCARD)/nRPIBOOT: J12.2, Module1.93 (nRPIBOOT)
/CM4_HighSpeed/CAM1_C_N: J8.15, Module1.127 (CAM1_C_N)
/CM4_HighSpeed/CAM1_C_P: J8.14, Module1.129 (CAM1_C_P)
/CM4_HighSpeed/CAM1_D0_N: J8.21, Module1.115 (CAM1_D0_N)
/CM4_HighSpeed/CAM1_D0_P: J8.20, Module1.117 (CAM1_D0_P)
/CM4_HighSpeed/CAM1_D1_N: J8.18, Module1.121 (CAM1_D1_N)
/CM4_HighSpeed/CAM1_D1_P: J8.17, Module1.123 (CAM1_D1_P)
/CM4_HighSpeed/CAM1_D2_N: J8.12, Module1.133 (CAM1_D2_N)
/CM4_HighSpeed/CAM1_D2_P: J8.11, Module1.135 (CAM1_D2_P)
/CM4_HighSpeed/CAM1_D3_N: J8.9, Module1.139 (CAM1_D3_N)
/CM4_HighSpeed/CAM1_D3_P: J8.8, Module1.141 (CAM1_D3_P)
/CM4_HighSpeed/CAM_GPIO: J8.6, Module1.97 (Camera_GPIO)
/CM4_HighSpeed/DSI1_C_N: J9.15, Module1.187 (DSI1_C_N)
/CM4_HighSpeed/DSI1_C_P: J9.14, Module1.189 (DSI1_C_P)
/CM4_HighSpeed/DSI1_D0_N: J9.21, Module1.175 (DSI1_D0_N)
/CM4_HighSpeed/DSI1_D0_P: J9.20, Module1.177 (DSI1_D0_P)
/CM4_HighSpeed/DSI1_D1_N: J9.18, Module1.181 (DSI1_D1_N)
/CM4_HighSpeed/DSI1_D1_P: J9.17, Module1.183 (DSI1_D1_P)
/CM4_HighSpeed/DSI1_D2_N: J9.12, Module1.193 (DSI1_D2_N)
/CM4_HighSpeed/DSI1_D2_P: J9.11, Module1.195 (DSI1_D2_P)
/CM4_HighSpeed/DSI1_D3_N: J9.9, Module1.194 (DSI1_D3_N)
/CM4_HighSpeed/DSI1_D3_P: J9.8, Module1.196 (DSI1_D3_P)
/CM4_HighSpeed/HDMI1_CEC: J11.13, Module1.149 (HDMI1_CEC)
/CM4_HighSpeed/HDMI1_CK_N: J11.12, Module1.166 (HDMI1_CLK_N)
/CM4_HighSpeed/HDMI1_CK_P: J11.10, Module1.164 (HDMI1_CLK_P)
/CM4_HighSpeed/HDMI1_D0_N: J11.9, Module1.160 (HDMI1_TX0_N)
/CM4_HighSpeed/HDMI1_D0_P: J11.7, Module1.158 (HDMI1_TX0_P)
/CM4_HighSpeed/HDMI1_D1_N: J11.6, Module1.154 (HDMI1_TX1_N)
/CM4_HighSpeed/HDMI1_D1_P: J11.4, Module1.152 (HDMI1_TX1_P)
/CM4_HighSpeed/HDMI1_D2_N: J11.3, Module1.148 (HDMI1_TX2_N)
/CM4_HighSpeed/HDMI1_D2_P: J11.1, Module1.146 (HDMI1_TX2_P)
/CM4_HighSpeed/HDMI1_HOTPLUG: J11.19, Module1.143 (HDMI1_HOTPLUG)
/CM4_HighSpeed/HDMI1_SCL: J11.15, Module1.147 (HDMI1_SCL)
/CM4_HighSpeed/HDMI1_SDA: J11.16, Module1.145 (HDMI1_SDA)
/CM4_HighSpeed/SCL0: J8.3, J9.3, Module1.80 (SCL0), R34.2
/CM4_HighSpeed/SDA0: J8.2, J9.2, Module1.82 (SDA0), R35.2
/CM4_HighSpeed/USB2_N: Module1.103 (USB2_N), U3.4 (D_N)
/CM4_HighSpeed/USB2_P: Module1.105 (USB2_P), U3.3 (D_P)
/CM4_HighSpeed/USBOTG_ID: Module1.101 (USB_OTG_ID), R12.1, R13.2, U3.2 (SEL)
/PCIE_CLK_N: J2.53 (REFCLKn), Module1.112 (PCIe_CLK_N)
/PCIE_CLK_P: J2.55 (REFCLKp), Module1.110 (PCIe_CLK_P)
/PCIE_RX_N: J2.41 (PERn0/SATA-B+), Module1.118 (PCIe_RX_N)
/PCIE_RX_P: J2.43 (PERp0/SATA-B-), Module1.116 (PCIe_RX_P)
/PCIE_TX_N: J2.47 (PETn0/SATA-A-), Module1.124 (PCIe_TX_N)
/PCIE_TX_P: J2.49 (PETp0/SATA-A+), Module1.122 (PCIe_TX_P)
/PCIE_nRST: J2.50 (~PERST), Module1.109 (PCIe_nRST)
/USB2-HUB/HD2_N: J5.2 (D-), U4.3 (USBDM_DN2/PRT_DIS_M2)
/USB2-HUB/HD2_P: J5.3 (D+), U4.4 (USBDP_DN2/PRT_DIS_P2)
/USB2-HUB/HD3_N: J6.2 (D-), U4.6 (USBDM_DN3/PRT_DIS_M3)
/USB2-HUB/HD3_P: J6.3 (D+), U4.7 (USBDP_DN3/PRT_DIS_P3)
/USB2-HUB/HD4_N: J4.2, J7.2 (D-), U4.8 (USBDM_DN4/PRT_DIS_M4)
/USB2-HUB/HD4_P: J4.3, J7.3 (D+), U4.9 (USBDP_DN4/PRT_DIS_P4)
/USB2-HUB/PWR1: U4.12 (PRTPWR1/BC_EN1), U6.3 (EN)
/USB2-HUB/USBD_N: J3.2 (D-), U3.8 (HSD1_M)
/USB2-HUB/USBD_P: J3.3 (D+), U3.9 (HSD1_P)
/USB2-HUB/USBH_N: U3.6 (HSD0_M), U4.30 (USBDM_UP)
/USB2-HUB/USBH_P: U3.7 (HSD0_P), U4.31 (USBDP_UP)
/USB2-HUB/VBUS: C28.1, C29.1, C30.1, C31.1, C32.1, J4.1, J5.1 (VBUS), J6.1 (VBUS), J7.1 (VBUS), U6.6 (OUT)
/USB2-HUB/nOCS1: U4.13 (OCS_N1), U4.17 (OCS_N2), U4.19 (OCS_N3), U4.21 (OCS_N4), U6.4 (nFault)
/nEXTRST: Module1.100 (nEXTRST), U4.26 (RESET_N)
GND: C1.2, C4.2, C5.2, C6.2, C7.2, C8.2, C9.2, C11.2, C12.2, C13.2, C14.2, C15.2, C16.2, C17.2, C18.2, C19.2, C20.2, C21.2, C22.2, C23.2, C24.2, C25.2, C26.2, C27.2, C28.2, C29.2, C30.2, C31.2, C32.2, C33.2, C34.2, C40.2, C41.2, FB2.2, J1.2, J2.3 (GND), J2.5 (GND), J2.11 (GND), J2.27 (GND), J2.33 (GND), J2.39 (GND), J2.45 (GND), J2.51 (GND), J2.57 (GND), J2.71 (GND), J2.73 (GND), J3.5 (GND), J3.6 (Shield), J4.4, J5.4 (GND), J5.5 (Shield), J6.4 (GND), J6.5 (Shield), J7.5 (GND), J7.6 (Shield), J8.4, J8.7, J8.10, J8.13, J8.16, J8.19, J8.22, J9.4, J9.7, J9.10, J9.13, J9.16, J9.19, J9.22, J10.0, J10.2, J10.5, J10.8, J10.11, J10.17, J11.0, J11.2, J11.5, J11.8, J11.11, J11.17, J12.1, J13.2, J14.2, J16.6 (VSS), J16.11 (SHIELD), J17.6, J17.9, J17.14, J17.20, J17.25, J17.30, J17.34, J17.39, J21.2, J21.6, Module1.1 (GND), Module1.2 (GND), Module1.7 (GND), Module1.8 (GND), Module1.13 (GND), Module1.14 (GND), Module1.22 (GND), Module1.23 (GND), Module1.32 (GND), Module1.33 (GND), Module1.42 (GND), Module1.43 (GND), Module1.52 (GND), Module1.53 (GND), Module1.59 (GND), Module1.60 (GND), Module1.65 (GND), Module1.66 (GND), Module1.71 (GND), Module1.74 (GND), Module1.98 (GND), Module1.107 (GND), Module1.108 (GND), Module1.113 (GND), Module1.114 (GND), Module1.119 (GND), Module1.120 (GND), Module1.125 (GND), Module1.126 (GND), Module1.131 (GND), Module1.132 (GND), Module1.137 (GND), Module1.138 (GND), Module1.144 (GND), Module1.150 (GND), Module1.155 (GND), Module1.156 (GND), Module1.161 (GND), Module1.162 (GND), Module1.167 (GND), Module1.168 (GND), Module1.173 (GND), Module1.174 (GND), Module1.179 (GND), Module1.180 (GND), Module1.185 (GND), Module1.186 (GND), Module1.191 (GND), Module1.192 (GND), Module1.197 (GND), Module1.198 (GND), R1.2, R10.2, R12.2, R14.2, R15.2, R16.2, R17.1, R18.2, R19.2, U1.3 (GND), U1.8 (GND), U2.7 (GND), U2.9 (EP), U3.5 (GND), U3.10 (nOE), U4.37 (VSS), U5.3 (GND), U5.8 (GND), U6.2 (GND), U7.3 (GND), U8.3 (GND), U10.3 (GND), U11.2 (GND), U12.19 (SHIELD), U12.20 (SHIELD), Y1.2, Y1.4
HDMI0_CEC: J10.13, Module1.151 (HDMI0_CEC)
HDMI0_CK_N: J10.12, Module1.190 (HDMI0_CLK_N)
HDMI0_CK_P: J10.10, Module1.188 (HDMI0_CLK_P)
HDMI0_D0_N: J10.9, Module1.184 (HDMI0_TX0_N)
HDMI0_D0_P: J10.7, Module1.182 (HDMI0_TX0_P)
HDMI0_D1_N: J10.6, Module1.178 (HDMI0_TX1_N)
HDMI0_D1_P: J10.4, Module1.176 (HDMI0_TX1_P)
HDMI0_D2_N: J10.3, Module1.172 (HDMI0_TX2_N)
HDMI0_D2_P: J10.1, Module1.170 (HDMI0_TX2_P)
HDMI0_HOTPLUG: J10.19, Module1.153 (HDMI0_HOTPLUG)
HDMI0_SCL: J10.15, Module1.200 (HDMI0_SCL)
HDMI0_SDA: J10.16, Module1.199 (HDMI0_SDA)
HDMI_5v: C34.1, J10.18, J11.18, R2.2, U7.2 (OUT)
unnamed: C10.1, R3.2
unnamed: C12.1, R4.2
unnamed: C36.1, C38.1, R21.2, R24.2
unnamed: C37.1, C39.1, R22.2, R25.2
unnamed: C2.2, D1.2 (A), Q1.4 (G), R1.1
unnamed: D3.1 (K), R20.1
unnamed: D4.1 (K), R23.1
unnamed: C3.1, C35.1, D5.2 (A), FB1.2, U9.5 (Vcc)
unnamed: D5.3 (K), J15.1
unnamed: C3.2, C35.2, C36.2, C37.2, D5.1 (K), FB2.1, J15.2, J19.2, R24.1, R25.1, R26.1, R27.1, U9.2 (GND)
unnamed: C1.1, J1.1, Q1.5 (D)
unnamed: J2.21 (CONFIG_0), R5.2
unnamed: J2.69 (CONFIG_1), R6.2
unnamed: J2.75 (CONFIG_2), R7.2
unnamed: J2.1 (CONFIG_3), R8.2
unnamed: J2.6 (~FULL_CARD_POWER_OFF), R11.1
unnamed: J3.1 (VBUS), R13.1
unnamed: J16.10 (DET_A), R28.2
unnamed: J16.9 (DET_B), R29.2
unnamed: J18.1, U8.4
unnamed: J15.6, J19.1
unnamed: J15.5, J19.3
unnamed: Module1.21 (PI_nLED_Activity), R20.2
unnamed: R23.2, U10.4
unnamed: C10.2, U2.1 (BST)
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

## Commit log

2022-03-28 Initial routing of high speed signals
    [CM4IOv5.kicad_pcb]
2022-03-28 Aditional routing
    [CM4IOv5.kicad_pcb]
2022-04-04 Adding normal size HDMI connectors
    [CM4IOv5.kicad_pcb, CM4IOv5.kicad_sch, CM4_GPIO.kicad_sch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]
2022-04-04 Adding 3D modesl
    [CM4IOv5.kicad_pcb, CM4IOv5.kicad_sch, CM4_GPIO.kicad_sch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]
2022-04-04 Routing High speed signals
    [CM4IOv5.kicad_pcb, CM4IOv5.kicad_sch, CM4_GPIO.kicad_sch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]
2022-04-04 Routing SD
    [CM4IOv5.kicad_pcb]
2022-04-04 Partialy routing GPIO
    [CM4IOv5.kicad_pcb]
2022-04-05 All wires connected
    [CM4IOv5.kicad_pcb]
2022-04-05 Completed initial routing
    [CM4IOv5.kicad_pcb]
2022-04-06 Tuning differential signals
    [CM4IOv5.kicad_pcb]
2022-04-06 Removing U1
    [CM4IOv5.kicad_pcb, CM4IOv5.kicad_sch, CM4_GPIO.kicad_sch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]
2022-04-06 Changing L2
    [CM4IOv5.kicad_pcb, CM4IOv5.kicad_sch]
2022-04-06 Fixing errors, fixing most warnings
    [CM4IOv5.kicad_pcb]
2022-04-06 Adding GlobalENable, and RpiBoot
    [CM4IOv5.kicad_pcb, CM4IOv5.kicad_sch, CM4_GPIO.kicad_sch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]
2022-04-11 Adding audio connector - fixing USB, adding logos
    [CM4IOv5.kicad_pcb, CM4IOv5.kicad_sch, CM4_GPIO.kicad_sch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]
2022-04-11 Directory structure change
    [CM4IOv5.csv, CM4IOv5.kicad_pcb, CM4IOv5.kicad_sch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]
2022-04-11 Renaming to Unifying
    [CM4IOv5.csv, Unifying.kicad_pcb, Unifying.kicad_sch]
2022-04-11 Removing logo
    [Unifying.kicad_pcb]
2022-04-11 New pictures
    [Unifying.kicad_pcb]
2022-04-15 Adding power layer filled zones
    [Unifying.kicad_pcb]
2022-04-15 Adding test production file
    [Unifying.kicad_pcb]
2022-05-25 Fixing remaining errors
    [CM4_GPIO.kicad_sch, CM4_HighSpeed.kicad_sch, USB2-HUB.kicad_sch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]
2022-06-08 Adding interactive BOM
2022-06-29 Adding latest version
    [Unifying-B_Cu.gbl, Unifying-B_Mask.gbs, Unifying-B_Paste.gbp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]
2022-06-29 Adding kitspace files
    [1-click-bom.tsv]
2022-06-29 Moving gerber files
    [Unifying-B_Cu.gbl, Unifying-B_Mask.gbs, Unifying-B_Paste.gbp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]
2022-07-10 Update part list
    [1-click-bom.tsv]
2022-10-05 Mirroring CAM, DSI, new GPDI pinout fix #2 #3 #5 #12
    [CM4_GPIO.kicad_sch, CM4_HighSpeed.kicad_sch, USB2-HUB.kicad_sch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]
2022-10-05 Adding changes to PCB, routing board
    [Unifying.kicad_pcb]
2022-10-06 Adding I2C poullups to schematics
    [CM4_GPIO.kicad_sch, CM4_HighSpeed.kicad_sch, Unifying.kicad_pcb]
2022-10-06 Adding I2C resistors on PCB - routing fix 4
    [Unifying.kicad_pcb]
2022-10-06 Adding ethernet connector to schematics
    [CM4_GPIO.kicad_sch, Unifying.kicad_pcb]
2022-10-06 Adding I2S MIC connector
    [CM4_GPIO.kicad_sch, Unifying.kicad_pcb]
2022-10-06 Cleaning all errors
    [Unifying.kicad_pcb]
2022-10-06 Initial routing of ethernet fix #13
    [Unifying.kicad_pcb]
2022-10-06 Adding MIC connector fix #14
    [Unifying.kicad_pcb]
2022-10-06 Routing GPIOs
    [Unifying.kicad_pcb]
2022-10-07 Rounting all signals fix #16
    [Unifying.kicad_pcb]
2022-10-07 Adding new BOM - fix #8
2022-10-07 Slightly improving routing
    [Unifying.kicad_pcb]
2022-10-07 Adding/moving some text fix #19
    [Unifying.kicad_pcb]
2022-10-07 Adding dimensions
    [Unifying.kicad_pcb]
2022-10-07 Tuning diff pair
    [Unifying.kicad_pcb]
2022-10-07 Tune skew - fix #17
    [Unifying.kicad_pcb]
2022-10-07 Connecting MIC fix #20
    [CM4_GPIO.kicad_sch, Unifying.kicad_pcb]
2022-10-07 Adding v02 production files
    [Unifying-B_Cu.gbl, Unifying-B_Mask.gbs, Unifying-B_Paste.gbp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]
